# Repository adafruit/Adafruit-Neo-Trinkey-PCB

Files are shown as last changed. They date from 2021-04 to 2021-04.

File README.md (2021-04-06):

## Adafruit Neo Trinkey PCB

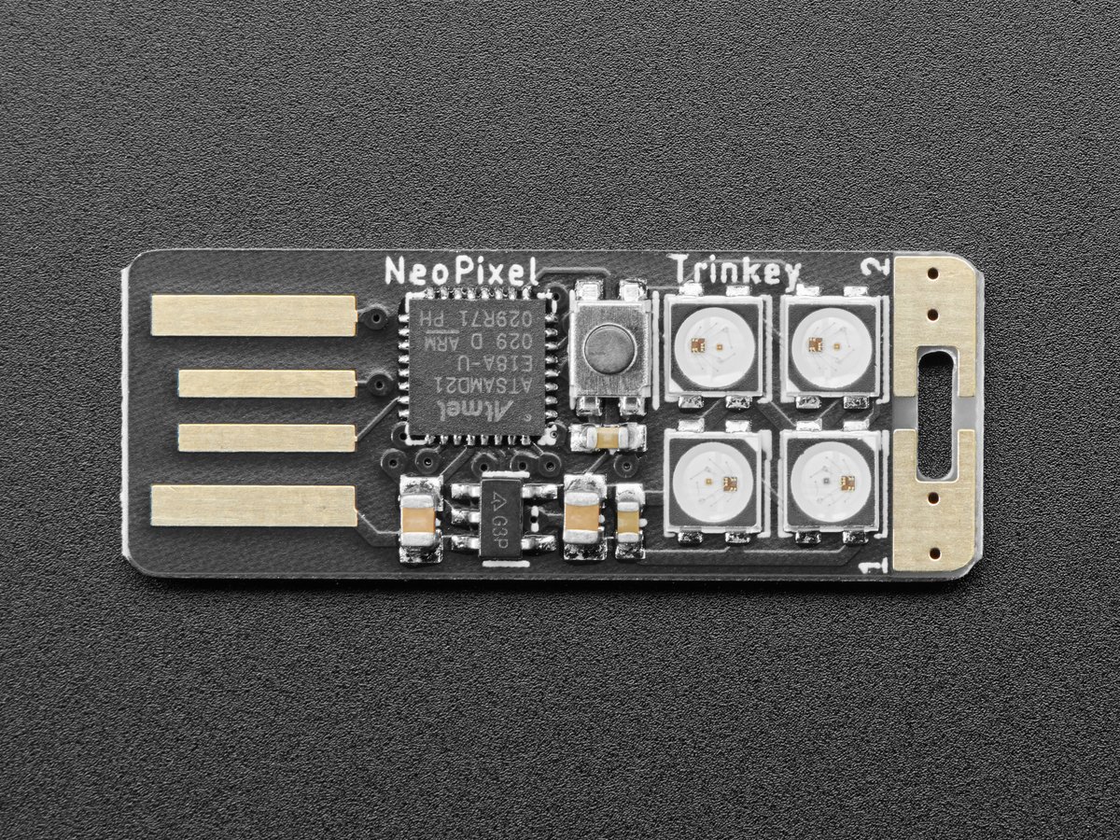
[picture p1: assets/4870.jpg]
<a href="http://www.adafruit.com/products/4870"><br/>
Click here to purchase one from the Adafruit shop</a>

PCB files for the Adafruit Neo Trinkey. 

Format is EagleCAD schematic and board layout
* https://www.adafruit.com/product/4870

### Description

It's half USB Key, half Adafruit Trinket...it's Neo Trinkey, the circuit board with a Trinket M0 heart and  four RGB NeoPixels for customizable glow. We were inspired by some USB key flashlight boards that would turn any battery pack into an LED torch. So we thought, hey what if we made something like that but with fully programmable color NeoPixels? And this is what we came up with!

The PCB is designed to slip into any USB A port on a computer or laptop. There's an ATSAMD21 microcontroller on board with just enough circuitry to keep it happy. One pin of the microcontroller connects to the four NeoPixel LEDs. Two other pins are used as capacitive touch inputs on the end - if you look carefully you can see the slotted end has left and right touch pads. A reset button lets you enter bootloader mode if necessary. That's it!

The SAMD21 can run CircuitPython or Arduino very nicely - with existing NeoPixel and our FreeTouch libraries for the capacitive touch input. Over the USB connection you can have serial, MIDI or HID connectivity. The Neo Trinkey is perfect for simple projects that can use a few user inputs and colorful outputs. Maybe you'll set it up as a simple status notifier, or stretch-break timer, or a macro keypad, or a random color generator, or, hey you could still make it into an LED flashlight if you wanted!

We think its just an adorable little board, small and durable and inexpensive enough that it could be a first microcontroller board, or inspiration for advanced developers to make something simple and fun.

* ATSAMD21E18 32-bit Cortex M0+ - 48 MHz 32 bit processor with 256KB Flash and 32 KB RAM
* Native USB supported by every OS - can be used in Arduino or CircuitPython as USB serial console, MIDI, Keyboard/Mouse HID, even a little disk drive for storing Python scripts.
* Can be used with Arduino IDE or CircuitPython
* Four RGB NeoPixel LEDs
* Two Capacitive Touch pads
* Reset switch for starting your project code over or entering bootloader mode
* Slim and cute, keychain-friendly!

### License

Adafruit invests time and resources providing this open source design, please support Adafruit and open-source hardware by purchasing products from [Adafruit](https://www.adafruit.com)!

Designed by Limor Fried/Ladyada for Adafruit Industries.

Creative Commons Attribution/Share-Alike, all text above must be included in any redistribution. 
See license.txt for additional details.

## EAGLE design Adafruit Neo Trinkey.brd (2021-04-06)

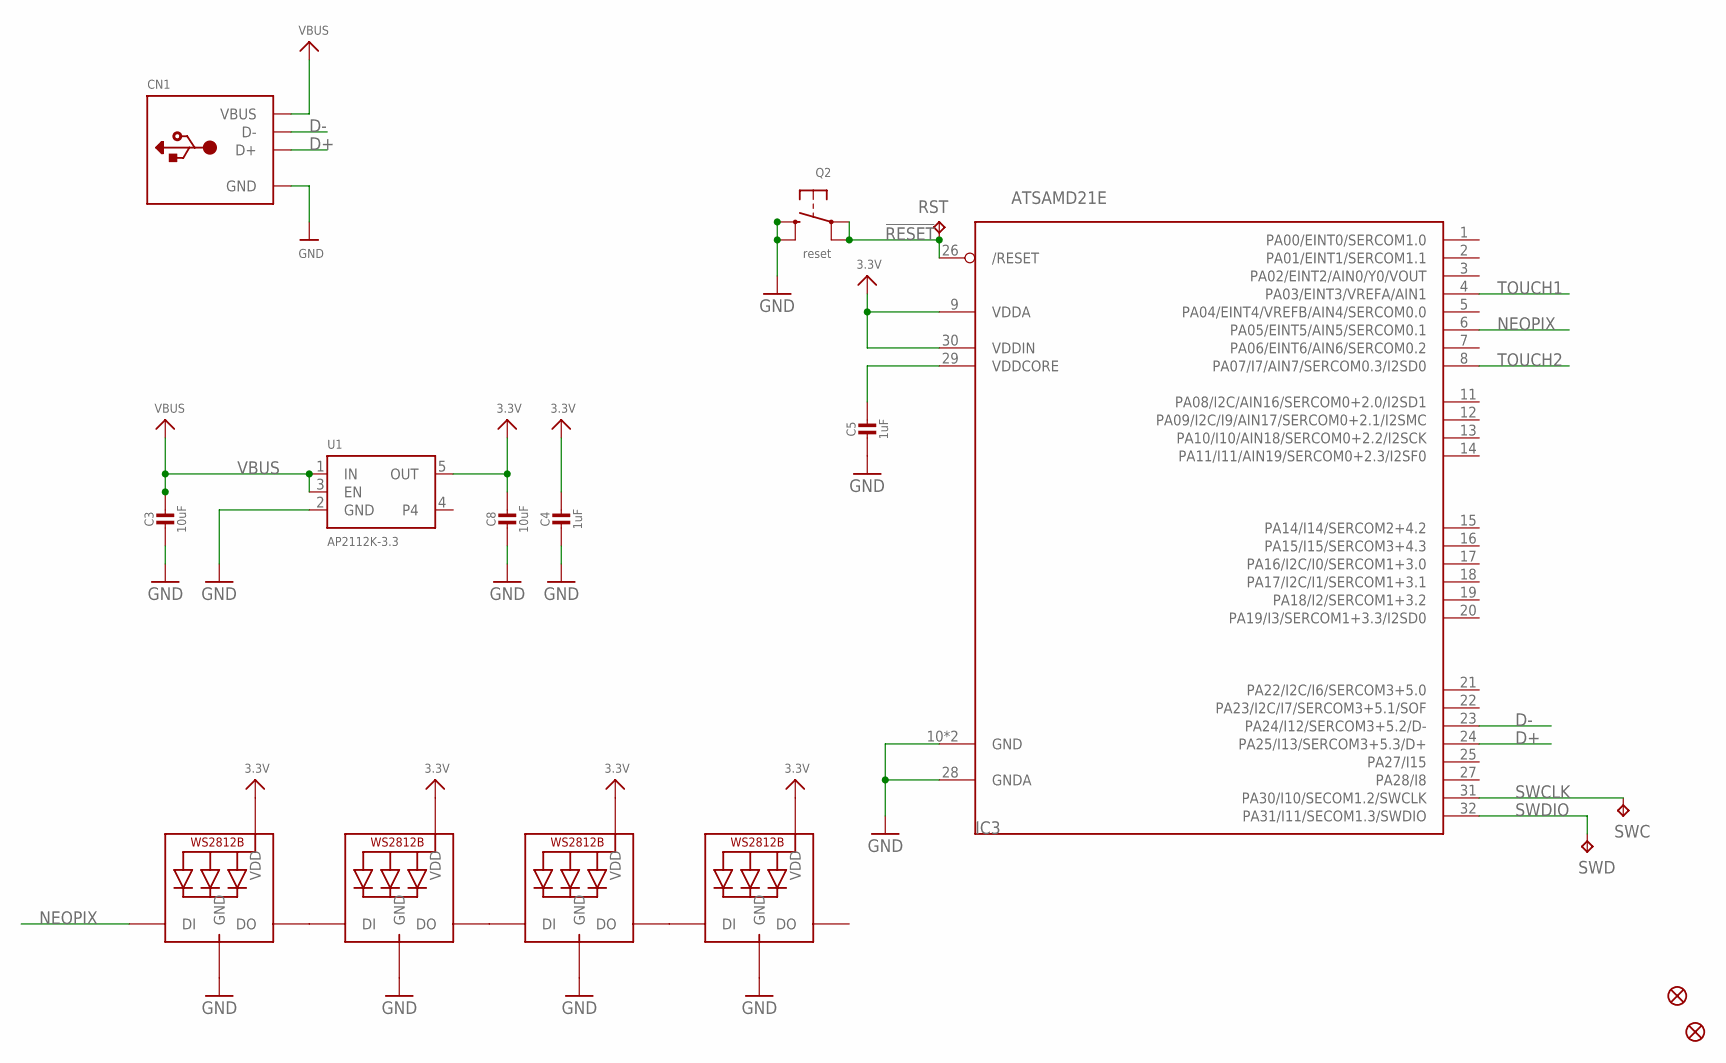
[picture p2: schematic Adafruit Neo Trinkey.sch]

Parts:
C3, C8: 10uF; 0805-NO
C4, C5: 1uF; 0603-NO
CN1: USB_TYPEAPCB; USBA_PCB
FID1, FID2: FIDUCIAL_1MM
IC3: ATSAMD21E; QFN32_5MM
LED1, LED2, LED3, LED4: WS2812B3535; LED3535
Q2: reset; BTN_KMR2_4.6X2.8
RST: TPTP16R; TP16R
SWC: TPTP15R; TP15R
SWD: TPTP16R; TP16R
U1: AP2112K-3.3; SOT23-5

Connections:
3.3V: C4.1, C8.1, IC3.9 (VDDA), IC3.30 (VDDIN), LED1.2 (VDD), LED2.2 (VDD), LED3.2 (VDD), LED4.2 (VDD), U1.5 (OUT)
!RESET: IC3.26 (/RESET), Q2.A, Q2.A' (P1), RST.TP
D+: CN1.USB_PLUS (D+), IC3.24 (PA25/I13/SERCOM3+5.3/D+)
D-: CN1.USB_NEG (D-), IC3.23 (PA24/I12/SERCOM3+5.2/D-)
GND: C3.2, C4.2, C5.2, C8.2, CN1.GND, IC3.10 (GND), IC3.28 (GNDA), IC3.33 (GND), LED1.4 (GND), LED2.4 (GND), LED3.4 (GND), LED4.4 (GND), Q2.B (S), Q2.B' (S1), U1.2 (GND)
unnamed: LED1.3 (DO), LED2.1 (DI)
unnamed: LED2.3 (DO), LED3.1 (DI)
unnamed: LED3.3 (DO), LED4.1 (DI)
NEOPIX: IC3.6 (PA05/EINT5/AIN5/SERCOM0.1), LED1.1 (DI)
SWCLK: IC3.31 (PA30/I10/SECOM1.2/SWCLK), SWC.TP
SWDIO: IC3.32 (PA31/I11/SECOM1.3/SWDIO), SWD.TP
TOUCH1: IC3.4 (PA03/EINT3/VREFA/AIN1)
TOUCH2: IC3.8 (PA07/I7/AIN7/SERCOM0.3/I2SD0)
VBUS: C3.1, CN1.VCC (VBUS), U1.1 (IN), U1.3 (EN)
VDDCORE1: C5.1, IC3.29 (VDDCORE)

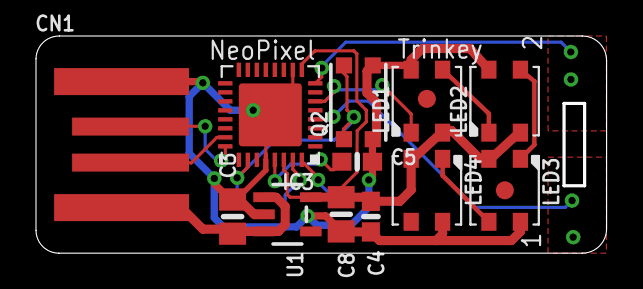
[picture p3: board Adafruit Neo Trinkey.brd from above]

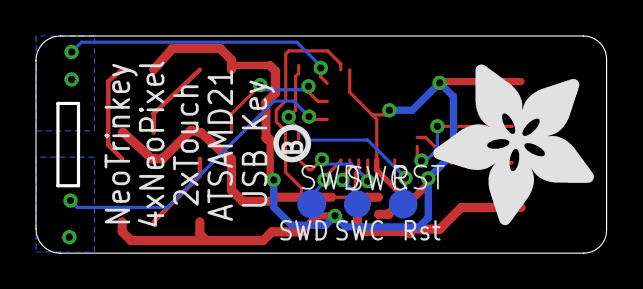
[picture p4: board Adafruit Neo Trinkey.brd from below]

Board: 2 copper layers, 31.7 x 12.1 mm, 19 parts (5 on the bottom side), 13 nets.

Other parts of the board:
U$8: PCBFEAT-REV-040
U$10: ADAFRUIT_9MM

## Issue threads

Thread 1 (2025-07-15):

Touch pad pin functions seem swapped in pinout diagram

vjou, 2025-07-15:
The touch pad assignments in Capacitive Touch Pads section (https://learn.adafruit.com/adafruit-neo-trinkey/pinouts#capacitive-touch-pads-3087047) correctly describe the TOUCH1 and TOUCH2 assignments, which correctly correspond to the silkscreen labels on the board.
But, in the pinout diagram, TOUCH1 and TOUCH2 assignments seem swapped, and they do not match the silkscreen labels.
I confirmed the pad with label 2 is connected to pin 8 (PA07) of SAMD21. So, all the functions on each pad might be swapped in the pinout diagram.

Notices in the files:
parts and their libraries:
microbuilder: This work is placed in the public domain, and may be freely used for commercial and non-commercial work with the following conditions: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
